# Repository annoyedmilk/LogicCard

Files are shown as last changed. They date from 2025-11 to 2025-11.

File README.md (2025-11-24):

# LogicCard




## Project Overview

The LogicCard is a compact and affordable FPGA development board featuring the Renesas SLG47910V FPGA with integrated USB programming via a CH552 microcontroller. The board includes an 11-pin Charlieplexed LED matrix (15×7 LEDs) and 4 user buttons, making it ideal for portable FPGA demonstrations and learning projects. The resistors for the LED matrix can be desoldered and the test points can be used for external applications.

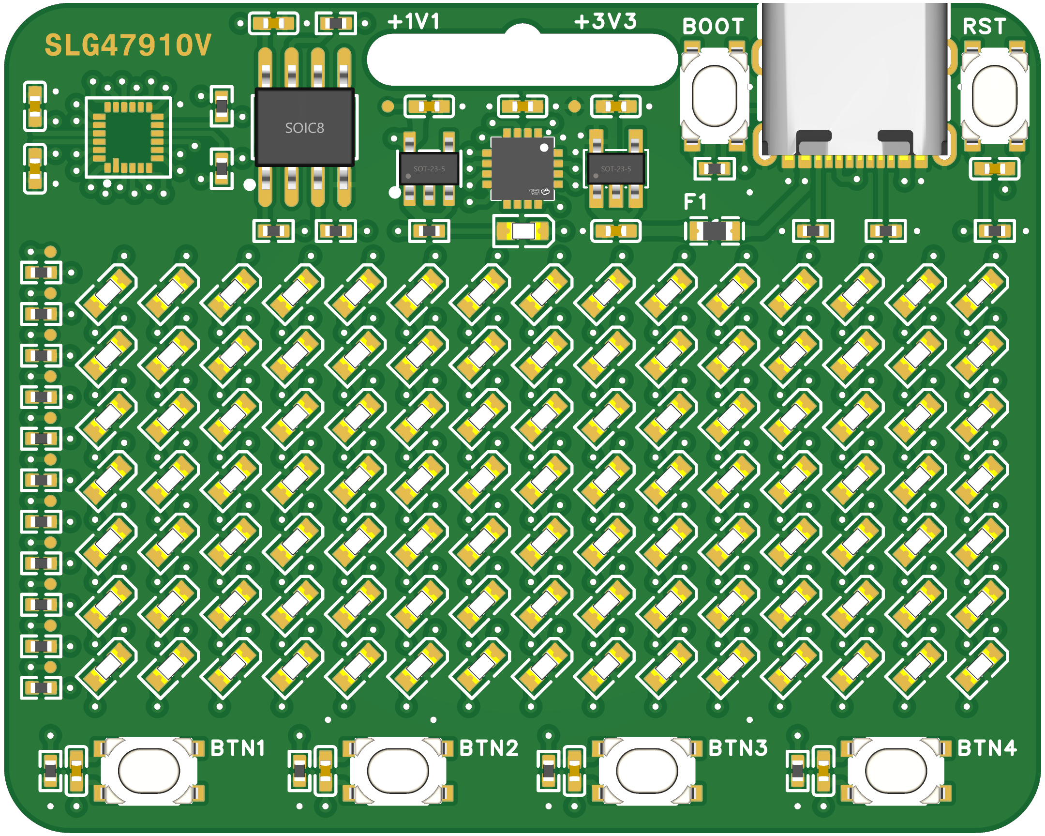
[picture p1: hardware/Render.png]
LogicCard 3D Render


### Key Features

- **FPGA**: Renesas SLG47910V (24-pin STQFN)
  - 1120 5-bit Look-Up Tables (LUTs)
  - 1120 D-type Flip-Flops (DFFs)
  - 5 kb distributed SRAM
  - 32 kb embedded Block RAM (BRAM)
  - 19 GPIOs available
  - 50 MHz on-chip oscillator
  - Phase-Locked Loop (PLL)
  - Advanced 6-input 2-output lookup table (LUT) structure for increased efficiency in high-usage designs
  - Low price that opens the low-density FPGA market to customers of all sizes (50 Cents at high volume)
  
- **USB Programming**: CH552 microcontroller implementing serprog protocol
- **Configuration Storage**: External SPI NOR Flash (W25Q80DVSNIG - 1 Mbit)
- **User Interface**: 15×7 LED matrix (105 LEDs) using 11 GPIO pins + 4 buttons
- **Power**: USB-powered with dual LDO regulation (5V → 3.3V → 1.1V)

---

## 2. Complete Pinout Tables

### 2.1 SLG47910V FPGA Pinout

| Pin | Name | Description | Net |
|-----|---|---|-----|
| 1 | GPIO10 | General Purpose I/O | CHRLY_2 |
| 2 | GPIO11 | General Purpose I/O | CHRLY_3 |
| 3 | GPIO12 | General Purpose I/O | CHRLY_4 |
| 4 | GPIO13 | General Purpose I/O | CHRLY_5 |
| 5 | GPIO14 | General Purpose I/O | CHRLY_6 |
| 6 | GPIO15 | General Purpose I/O | CHRLY_7 |
| 7 | GPIO16 | General Purpose I/O | CHRLY_8 |
| 8 | GPIO17 | General Purpose I/O | CHRLY_9 |
| 9 | GPIO18 | General Purpose I/O | CHRLY_10 |
| 10 | EN(nSLEEP) | Enable / Sleep (active low) | FPGA_EN |
| 11 | PWR(nRST) | Power / Reset (active low) | FPGA_RST |
| 12 | GND | Ground | GND |
| 13 | GPIO0 | General Purpose I/O | BUTTON_1 |
| 14 | GPIO1 | General Purpose I/O | BUTTON_2 |
| 15 | GPIO2 | General Purpose I/O | BUTTON_3 |
| 16 | GPIO3/SPI_CLK | GPIO 3 / SPI Clock | SPI_SCK |
| 17 | GPIO4/SPI_SS | GPIO 4 / SPI Chip Select | SPI_CS |
| 18 | GPIO5/SPI_SI | GPIO 5 / SPI Slave In | SPI_MISO |
| 19 | GPIO6/SPI_SO | GPIO 6 / SPI Slave Out | SPI_MOSI |
| 20 | GPIO7 | General Purpose I/O | BUTTON_4 |
| 21 | VDDIO | I/O Supply Voltage | +3.3V |
| 22 | VDDC | Core Supply Voltage | +1.1V |
| 23 | GPIO8 | General Purpose I/O | CHRLY_0 |
| 24 | GPIO9 | General Purpose I/O | CHRLY_1 |

### 2.2 CH552 Microcontroller Pinout

| Pin | Name | Description | Net |
|-----|---|---|-----|
| 1 | V33 | Internal USB power regulator | +3.3V |
| 2 | MOSI/PWM1/TIN3 | Port 1.5 | SPI_MOSI |
| 3 | T2_/CAP1_/SCS | Port 1.4 | SPI_CS |
| 4 | TXD1_/INT0/VBUS1 | Port 3.2 | LED |
| 5 | MISO/RXD1/TIN4 | Port 1.6 | SPI_MISO |
| 6 | SCK/TXD1/TIN5 | Port 1.7 | SPI_SCK |
| 7 | RST/T2EX_/CAP2_ | Reset | Reset |
| 8 | T2/CAP1/TIN0 | Port 1.0 | FPGA_RST |
| 9 | PWM2_/TXD | Port 3.1 | NC |
| 10 | PWM1_/RXD | Port 3.0 | NC |
| 11 | T2EX/CAP2/TIN1 | Port 1.1 | NC |
| 12 | INT1 | Port 3.3 | FPGA_EN |
| 13 | PWM2/RXD1_/T0 | Port 3.4 | NC |
| 14 | UDP | Port 3.6 | USB_D+ |
| 15 | UDM | Port 3.7 | USB_D- |
| 16 | VCC/VDD | Power | +3.3V |
| 17 | GND/VSS | GND | GND |

### 2.3 W25Q80DVSNIG Flash Memory Pinout

| Pin | Name | Description | Net |
|-----|---|---|-----|
| 1 | /CS | Chip Select (active low) | SPI_CS |
| 2 | DO(IO1) | Data Out / I/O 1 | SPI_MISO |
| 3 | /WP(IO2) | Write Protect (active low) / I/O 2 | Pull-up +3.3V |
| 4 | GND | Ground | GND |
| 5 | DI(IO0) | Data In / I/O 0 | SPI_MOSI |
| 6 | CLK | Clock | SPI_SCK |
| 7 | /HOLD(IO3) | Hold (active low) / I/O 3 | Pull-up +3.3V |
| 8 | VCC | Supply Voltage | +3.3V |

### 2.4 LED Matrix Charlieplex Connections

| FPGA GPIO | FPGA Pin | Matrix Pin | Function |
|---|---|---|---|
| GPIO8 | 23 | CHRLY_1 | Charlieplex Pin 1 |
| GPIO9 | 24 | CHRLY_2 | Charlieplex Pin 2 |
| GPIO10 | 1 | CHRLY_3 | Charlieplex Pin 3 |
| GPIO11 | 2 | CHRLY_4 | Charlieplex Pin 4 |
| GPIO12 | 3 | CHRLY_5 | Charlieplex Pin 5 |
| GPIO13 | 4 | CHRLY_6 | Charlieplex Pin 6 |
| GPIO14 | 5 | CHRLY_7 | Charlieplex Pin 7 |
| GPIO15 | 6 | CHRLY_8 | Charlieplex Pin 8 |
| GPIO16 | 7 | CHRLY_9 | Charlieplex Pin 9 |
| GPIO17 | 8 | CHRLY_10 | Charlieplex Pin 10 |
| GPIO18 | 9 | CHRLY_11 | Charlieplex Pin 11 |

### 2.5 User Button Connections

| Button | FPGA GPIO | FPGA Pin |
|---|---|---|
| BUTTON_1 | GPIO0 | 13 |
| BUTTON_2 | GPIO1 | 14 |
| BUTTON_3 | GPIO2 | 15 |
| BUTTON_4 | GPIO7 | 20 |

---

## 3. Configuration and Programming

### 3.1 Configuration Mode

The SLG47910V is configured to use **External SPI Flash Mode** (SPI Master):
- FPGA acts as SPI Master during configuration
- External SPI Flash (W25Q80) acts as SPI Slave
- GPIO4 (SPI_SS) has a 10kΩ pull-up ensuring HIGH at power-up

### 3.2 Programming Sequence

**Typical Operation Sequence:**
1. MCU asserts FPGA_RST to hold FPGA in reset
2. MCU takes control of SPI bus and writes configuration data to Flash
3. MCU releases FPGA_RST
4. FPGA boots and reads configuration from the same SPI Flash
5. FPGA becomes operational

### 3.3 Bitstream Size

- Required: **384 kbit** (48 KB) for full configuration
- Available: **1 Mbit** (128 KB) in W25Q80 Flash

---

## 4. LED Matrix Operation

### 4.1 Charlieplexing Details

The 15×7 LED matrix (105 LEDs) is controlled using **11 GPIO pins** via Charlieplexing:

**Formula:**
```
Maximum LEDs = n × (n - 1)
With 11 pins: 11 × 10 = 110 possible LEDs
Actual usage: 105 LEDs (15 rows × 7 columns)
```

### 4.2 Current Limiting

Each Charlieplex pin should have a series resistor (82Ω) for current limiting:
- Forward voltage (VF): ~1.8V (yellow LEDs)
- Forward current (IF): ~10 mA for visibility
- These resistors can be desoldered to use test points for external applications
- As one GPIO drives the anode and another the cathode, the total resistance is 2 × 82Ω = 164Ω

---

## 5. CH552 USB Programmer

### 5.1 serprog Protocol Implementation

The CH552 firmware implements the serprog protocol for flashrom compatibility:

**Supported Features:**
- SPI Master interface
- FPGA reset/enable control with bus arbitration
- Visual LED feedback during programming operations
- Compatible with standard flashrom tool

**USB Identifiers:**
- Vendor ID: 0x1a86 (WCH)
- Product ID: 0x5722
- Device Class: CDC
- Product String: "ch552-serprog"

**LED Behavior:**
- **On** during power-up and USB enumeration
- **Blinks** during USB configuration
- **Off** when idle and ready for commands
- **On** during flash programming operations (CH552 controls SPI bus)
- **Off** when FPGA is enabled (FPGA controls SPI bus)

### 5.2 Programming Commands

```bash
# Flash FPGA bitstream using flashrom
flashrom -p serprog:dev=/dev/ttyACM0 -w FPGA_bitstream_FLASH_MEM.bin

# Read current configuration
flashrom -p serprog:dev=/dev/ttyACM0 -r current_config.bin

# Erase flash
flashrom -p serprog:dev=/dev/ttyACM0 -E
```

---

## 6. Available FPGA Examples

The project includes two ready-to-use FPGA bitstreams:

### 6.1 Blink Example
- **Location**: [examples/blink/](examples/blink/)
- **Description**: Simple LED blinking demo using Charlieplex configuration
- **Features**: Single LED blinking at 2Hz using 2 GPIO pins
- **Bitstream**: [examples/blink/ffpga/build/bitstream/FPGA_bitstream_FLASH_MEM_1MB.bin](examples/blink/ffpga/build/bitstream/FPGA_bitstream_FLASH_MEM_1MB.bin)

### 6.2 Demo Project
- **Location**: [examples/demo/demo.ffpga](examples/demo/demo.ffpga)
- **Description**: Full 15×7 LED matrix with ripple effect animation
- **Features**:
  - 105-LED Charlieplexed matrix (15 rows × 7 columns)
  - Button controls for pattern inversion, speed control, and pause/play
  - Uses all 11 Charlieplex GPIO pins
- **Bitstream**: [examples/demo/ffpga/build/bitstream/FPGA_bitstream_FLASH_MEM_1MB.bin](examples/demo/ffpga/build/bitstream/FPGA_bitstream_FLASH_MEM_1MB.bin)

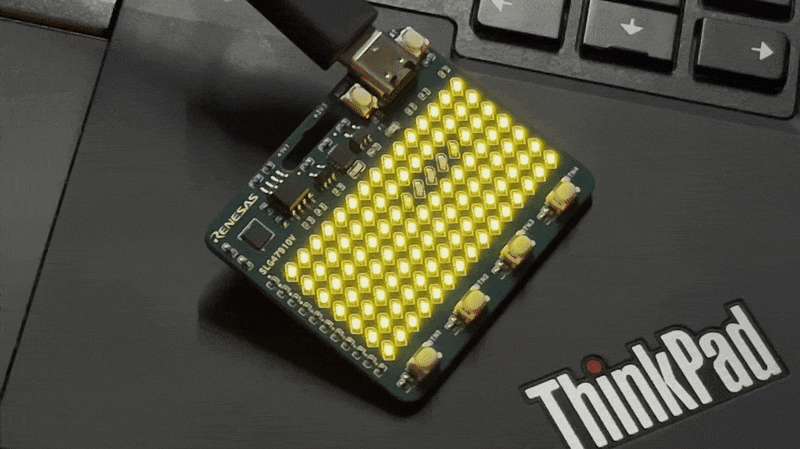
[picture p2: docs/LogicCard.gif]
LogicCard Demo Animation


---

## 7. Design Files Structure

```
LogicCard/
├── hardware/               # Hardware design files
│   ├── BOM.csv            # Bill of Materials
│   ├── Schematic.pdf      # Circuit schematic
│   ├── 3D.step            # 3D model (STEP format)
│   └── Render.png         # 3D render preview
├── firmware/              # CH552 firmware source code
│   ├── ch552_serprog/     # serprog protocol implementation
│   │   └── main.c         # Main firmware source
│   ├── include/           # Shared header files
│   └── build/             # Compiled firmware binaries
│       └── ch552-serprog.bin
├── examples/              # Example FPGA projects
│   ├── blink/             # Simple LED blink example
│   │   ├── blink.ffpga    # GoConfigure project file
│   │   └── ffpga/         # FFPGA build artifacts
│   │       ├── src/       # Verilog source files
│   │       │   └── blink.v
│   │       └── build/     # Build output directory
│   │           └── bitstream/
│   │               ├── FPGA_bitstream_FLASH_MEM.bin (48KB)
│   │               └── FPGA_bitstream_FLASH_MEM_1MB.bin (1MB padded)
│   └── demo/              # LED matrix demo with ripple effect
│       ├── demo.ffpga     # GoConfigure project file
│       └── ffpga/         # FFPGA build artifacts
│           ├── src/       # Verilog source files
│           │   └── demo.v
│           └── build/     # Build output directory
│               └── bitstream/
│                   ├── FPGA_bitstream_FLASH_MEM.bin (48KB)
│                   └── FPGA_bitstream_FLASH_MEM_1MB.bin (1MB padded)
└── docs/                  # Documentation and datasheets
    ├── CH552.PDF          # CH552 microcontroller datasheet
    ├── SLG47910.pdf       # SLG47910V FPGA datasheet
    ├── W25Q80DV.pdf       # W25Q80 Flash memory datasheet
    └── LogicCard.gif      # Demo animation
```

---

## 8. Quick Start Guide

### 8.1 Hardware Setup
1. Connect LogicCard to computer via USB-C cable
2. The board should enumerate as a USB device

### 8.2 CH552 Firmware Update (First Time Setup)

The CH552 microcontroller needs to be programmed with the serprog firmware on first use.

#### Installing wchisp (Recommended for Linux)

```bash
# Install from cargo (Rust package manager)
cargo install wchisp

# Set udev rules for non-root access
sudo tee /etc/udev/rules.d/50-wchisp.rules > /dev/null <<EOF
SUBSYSTEM=="usb", ATTRS{idVendor}=="4348", ATTRS{idProduct}=="55e0", MODE="0666"
EOF
sudo udevadm control --reload-rules
```

**Arch Linux:**
```bash
yay -S wchisp
```

#### Flashing CH552 Firmware

1. Hold the BOOT button and connect the board to your computer
2. Flash the firmware:
   ```bash
   wchisp flash firmware/build/ch552-serprog.bin
   ```
3. Disconnect and reconnect the board (without holding BOOT)
4. The board should now appear as `/dev/ttyACM0`

For more details on wchisp, see the [official repository](https://github.com/ch32-rs/wchisp).

### 8.3 Programming the FPGA

#### Try the Pre-built Examples

1. Install flashrom:
   ```bash
   sudo apt install flashrom
   ```

2. Flash one of the ready-to-use examples:
   ```bash
   # Blink example
   flashrom -p serprog:dev=/dev/ttyACM0 -w examples/blink/ffpga/build/bitstream/FPGA_bitstream_FLASH_MEM_1MB.bin

   # Or the full LED matrix demo
   flashrom -p serprog:dev=/dev/ttyACM0 -w examples/demo/ffpga/build/bitstream/FPGA_bitstream_FLASH_MEM_1MB.bin
   ```

3. The FPGA automatically configures and runs after programming

#### Build Your Own FPGA Design

1. Create your design using Renesas GoConfigure tool
2. Generate bitstream file (`.bin`)
3. **Pad the bitstream to 1MB** (flashrom requires full chip-size images):
   ```bash
   # Pad bitstream to match W25Q80 flash size (1MB)
   cp FPGA_bitstream_FLASH_MEM.bin FPGA_bitstream_FLASH_MEM_1MB.bin
   truncate -s 1M FPGA_bitstream_FLASH_MEM_1MB.bin
   ```
4. Flash using: `flashrom -p serprog:dev=/dev/ttyACM0 -w FPGA_bitstream_FLASH_MEM_1MB.bin`

**Note:** The FPGA only uses the first 48KB (384 kbit) of the flash for configuration. The W25Q80 flash chip is 1MB (1,048,576 bytes), so flashrom requires the image to be padded to the full chip size.

---

## 9. Specifications Summary

| Parameter | Value |
|---|---|
| FPGA Logic | 1120 LUTs, 1120 DFFs |
| Memory | 5kb SRAM + 32kb BRAM |
| I/O Pins | 19 GPIOs |
| Clock | 50 MHz internal oscillator + PLL |
| Flash Storage | 1 Mbit SPI NOR (W25Q80) |
| USB Interface | Full Speed (12 Mbps) |
| LED Matrix | 15×7 (105 LEDs) |
| User Buttons | 4 |
| Power | USB 5V → 3.3V (TLV70233) → 1.1V (TLV74311) |
| Voltage Regulators | TLV70233DBVR (3.3V), TLV74311PDBVR (1.1V) |
| Programming | serprog/flashrom compatible |

---

## 10. Contributing

This is an open-source hardware project. Contributions, suggestions, and feedback are welcome!

### How to Contribute
- Report issues or suggest features via GitHub Issues
- Submit pull requests for improvements
- Help improve documentation

---

## 11. Resources & References

### Datasheets
- [SLG47910V Datasheet](https://www.renesas.com/document/dst/slg47910-datasheet) - Renesas FPGA
- [W25Q80DV Datasheet](https://www.winbond.com/resource-files/w25q80dv_revg_07212015.pdf) - Flash Memory
- [CH552 Datasheet](https://www.wch-ic.com/downloads/CH552DS1_PDF.html) - USB MCU

### Software Tools
- [GoConfigure](https://www.renesas.com/en/software-tool/go-configure-software-hub): Official Renesas FPGA development tool
- [flashrom](https://github.com/flashrom/flashrom): Open-source flash programmer
- [SDCC](https://sdcc.sourceforge.net/): Small Device C Compiler for CH552

### Example Code
- [ch552_serprog](https://github.com/ieiao/ch554_sdcc) - CH552 serprog implementation
- [Charlieplexing Examples](https://en.wikipedia.org/wiki/Charlieplexing) - LED matrix control

### Alternative Development Workflows
- [LogicCard-VHDL](https://github.com/annoyedmilk/LogicCard-VHDL) - VHDL synthesis workflow using GHDL/Yosys for those who prefer VHDL over Verilog

---

## 12. License

This project is licensed under the **CERN Open Hardware Licence Version 2 - Weakly Reciprocal (CERN-OHL-W)**. See the [LICENSE](LICENSE) file for full details.

## 13. Credits & Acknowledgments

- **Renesas** for providing SLG47910V FPGA samples and development tools
- **ieiao** for the [CH552 serprog implementation](https://github.com/ieiao/ch554_sdcc)
- **ch32-rs team** for the [wchisp tool](https://github.com/ch32-rs/wchisp)
- The open-source hardware and FPGA community

## 14. Contact & Support

For questions, issues, or suggestions:
- Open an issue on GitHub
- Check the [docs/](docs/) folder for datasheets and technical documentation
- Review the schematic and BOM in the [hardware/](hardware/) folder

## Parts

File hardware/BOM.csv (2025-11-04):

No. | Quantity | Comment | Designator | Footprint | Value | Manufacturer Part | Manufacturer | Supplier Part | Supplier
1 | 13 | Test-Point | +1V1,+3V3,TP1,TP2,TP3,TP4,TP5,TP6,TP7,TP8,TP9,TP10,TP11 | Test-Point-0.5mm
2 | 6 | SKRPACE010 | BOOT,BTN1,BTN2,BTN3,BTN4,RST | KEY-SMD_4P-L4.2-W3.2-P2.20-LS4.6 |  | SKRPACE010 | ALPSALPINE(阿尔卑斯阿尔派) | C139797 | LCSC
3 | 1 | TYPE-C 16PIN 2MD(073) | C1 | USB-C-SMD_TYPE-C-6PIN-2MD-073 |  | TYPE-C 16PIN 2MD(073) | SHOU HAN(首韩) | C2765186 | LCSC
4 | 12 | 1uF | C5,C6,C8,C9,C10,C11,C12,C14,C15,C16,C17,C18 | C0402 | 1uF | GRM155Z71A105KE01D | muRata(村田) | C528974 | LCSC
5 | 1 | MF-FSMF035X-2 | F1 | F0603 |  | MF-FSMF035X-2 | BOURNS | C116602 | LCSC
6 | 106 | 19-213/Y2C-CQ2R2L/3T(CY) | LED1,LED2,LED3,LED4,LED5,LED6,LED7,LED8,LED9,LED10,LED11,LED12,LED13,LED14,LED15,LED16,LED17,LED18,LED19,LED20,LED21,LED22,LED23,LED24,LED25,LED26,LED27,LED28,LED29,LED30,LED31,LED32,LED33,LED34,LED35,LED36,LED37,LED38,LED39,LED40,LED41,LED42,LED43,LED44,LED45,LED46,LED47,LED48,LED49,LED50,LED51,LED52,LED53,LED54,LED55,LED56,LED57,LED58,LED59,LED60,LED61,LED62,LED63,LED64,LED65,LED66,LED67,LED68,LED69,LED70,LED71,LED72,LED73,LED74,LED75,LED76,LED77,LED78,LED79,LED80,LED81,LED82,LED83,LED84,LED85,LED86,LED87,LED88,LED89,LED90,LED91,LED92,LED93,LED94,LED95,LED96,LED97,LED98,LED99,LED100,LED101,LED102,LED103,LED104,LED105,LED106 | LED0603-RD-YELLOW |  | 19-213/Y2C-CQ2R2L/3T(CY) | EVERLIGHT(亿光) | C72038 | LCSC
7 | 2 | 5.1kΩ | R18,R19 | R0402 | 5.1kΩ | RC0402JR-075K1L | YAGEO(国巨) | C105873 | LCSC
8 | 11 | 10kΩ | R23,R24,R36,R37,R38,R39,R53,R54,R55,R56,R57 | R0402 | 10kΩ | RC0402FR-0710KL | YAGEO(国巨) | C60490 | LCSC
9 | 11 | 82Ω | R41,R42,R43,R44,R45,R46,R47,R48,R49,R50,R51 | R0402 | 82Ω | RC0402FR-0782RL | YAGEO(国巨) | C163453 | LCSC
10 | 1 | 180Ω | R52 | R0402 | 180Ω | RC0402FR-07180RL | YAGEO(国巨) | C138045 | LCSC
11 | 1 | SLG47910V | U1 | STQFN-24_L3.0-W3.0-P0.4_SLG47910V |  | SLG47910V |  | C9900234634 | LCSC
12 | 1 | CH552P | U2 | VQFN-16_L3.0-W3.0-P0.50-BL-EP1.7 |  | CH552P | WCH(南京沁恒) | C968536 | LCSC
13 | 1 | W25Q80DVSNIG | U3 | SOIC-8_L4.9-W3.9-P1.27-LS6.0-BL |  | W25Q80DVSNIG | Winbond(华邦) | C115408 | LCSC
14 | 1 | TLV70233DBVR | U4 | SOT-23-5_L3.0-W1.7-P0.95-LS2.8-BR |  | TLV70233DBVR | TI(德州仪器) | C26833 | LCSC
15 | 1 | TLV74311PDBVR | U5 | SOT-23-5_L3.0-W1.7-P0.95-LS2.8-BL |  | TLV74311PDBVR | TI(德州仪器) | C485147 | LCSC

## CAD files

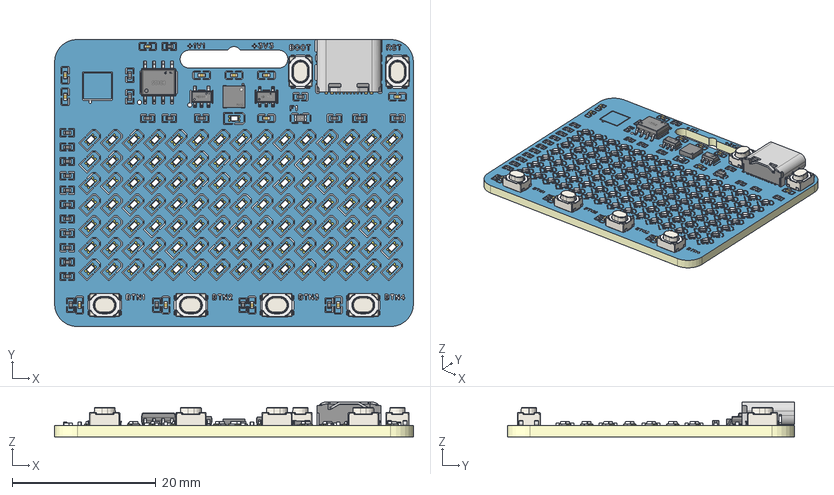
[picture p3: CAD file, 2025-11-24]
hardware/3D.step
50.0 x 40.0 x 4.87 mm
Board~ELZ3
TopCopper~ELZ3
BottomCopper~ELZ3
TopSilkscreen~ELZ3
BottomSilkscreen~ELZ3
TopFpcStiffener~ELZ3
BottomFpcStiffener~ELZ3
R0402~R0402_L1.0-W0.5-H0.4~ELZ3 x 25
F0603~F0603_L1.7-W0.9-H0.7~ELZ3
KEY-SMD_4P-L4.2-W3.2-P2.20-LS4.6~KEY-SMD_ 4P-L4.2-W3.2-H2.5-LS4.6-P2.2~ELZ3 x 6
USB-C-SMD_TYPE-C-6PIN-2MD-073~USB-C-SMD_TYPE-C-6PIN-2MD-073~ELZ3
C0402~C0402_L1.0-W0.5-H0.5~ELZ3 x 12
SOT-23-5_L3.0-W1.7-P0.95-LS2.8-BR~SOT-23-5_ L2.9-W1.6-H1.1-LS2.8-P0.95~ELZ3
SOT-23-5_L3.0-W1.7-P0.95-LS2.8-BL~SOT-23-5_ L2.9-W1.6-H1.1-LS2.8-P0.95~ELZ3
SOIC-8_L4.9-W3.9-P1.27-LS6.0-BL~SOIC-8_L4.9-W3.9-H1.7-LS6.0-P1.27~ELZ3
VQFN-16_L3.0-W3.0-P0.50-BL-EP1.7~VQFN-16_L3.0-W3.0-P0.50-BL-EP1.7~ELZ3
LED0603-RD-YELLOW~LED0603-RD-YELLOW~ELZ3 x 106

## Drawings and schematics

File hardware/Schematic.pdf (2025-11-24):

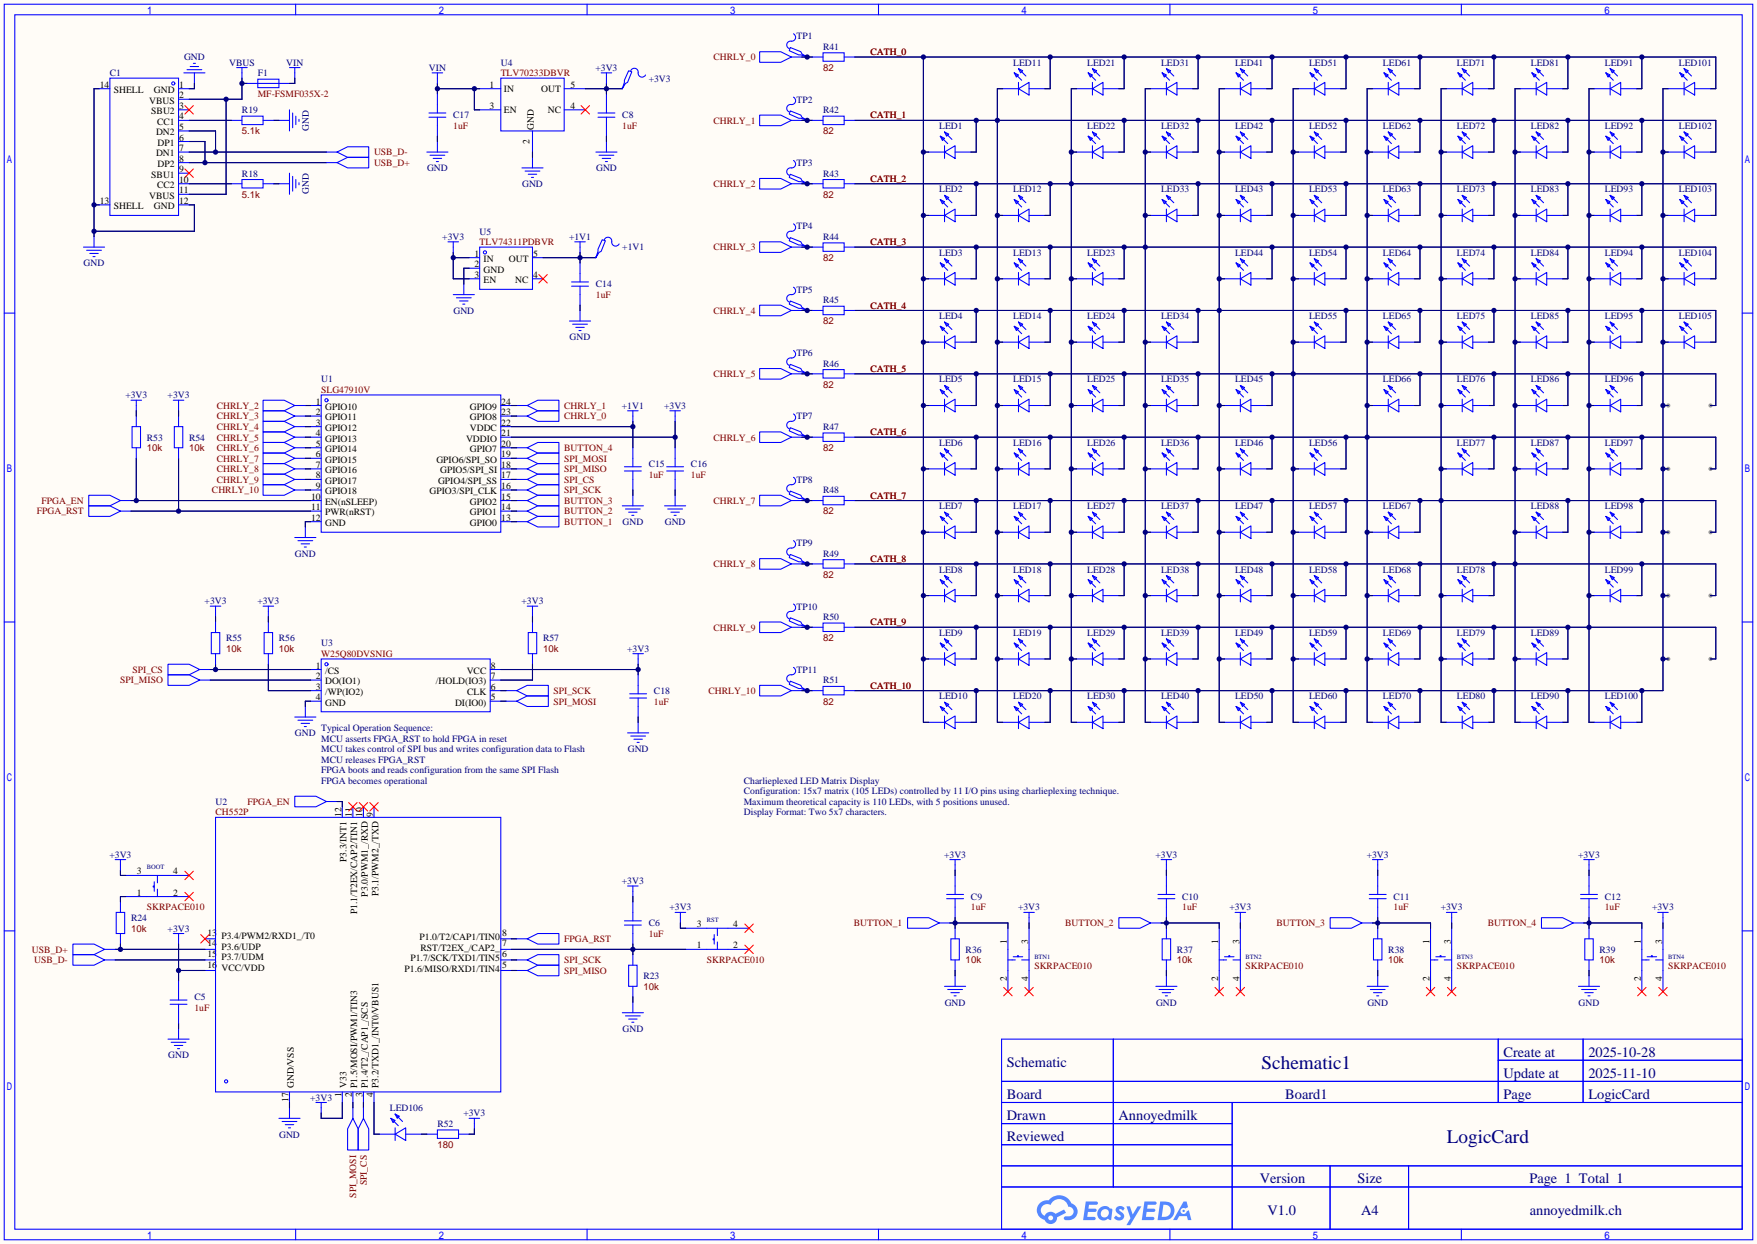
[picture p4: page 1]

Typical Operation Sequence:
GND
MCU asserts FPGA_RST to hold FPGA in reset
MCU takes control of SPI bus and writes configuration data to Flash
MCU releases FPGA_RST
FPGA boots and reads configuration from the same SPI Flash

Configuration: 15x7 matrix (105 LEDs) controlled by 11 I/O pins using charlieplexing technique.
Maximum theoretical capacity is 110 LEDs, with 5 positions unused.
Display Format: Two 5x7 characters.

Schematic | Schematic1 | Create at | 2025-10-28

Update at | 2025-11-10

Board | Board1 | Page | LogicCard
Drawn | Annoyedmilk | LogicCard
Reviewed

Version | Size | Page 1 Total 1

V1.0 | A4 | annoyedmilk.ch

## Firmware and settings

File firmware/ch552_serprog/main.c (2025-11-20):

/********************************** (C) COPYRIGHT *******************************
* File Name          : CDC.C
* Author             : ieiao
* Modified by        : annoyedmilk
* Version            : V1.1
* Date               : 2017/03/01
* Modified Date      : 2025/11/03
* Description        : CH552 serprog implementation for use with flashrom
*                      V1.1: Added FPGA reset/enable control for LogicCard project
*                            - FPGA_RST (Port 1.0) and FPGA_EN (Port 3.3) control
*                            - Automatic FPGA reset before flash operations
*                            - Automatic FPGA enable after flash programming
*                            - LED activity indicator (active low)
*******************************************************************************/
#include <stdint.h>
#include <stdio.h>
#include <string.h>

#include <ch554.h>
#include <ch554_usb.h>
#include <spi.h>
#include <debug.h>
#include "serprog.h"

#define LED_PIN  2
SBIT(LED, 0xb0, LED_PIN);     // Port 3.2 - LED
#define CS_PIN  4
SBIT(CS, 0x90, CS_PIN);       // Port 1.4 - SPI_CS
#define FPGA_RST_PIN  0
SBIT(FPGA_RST, 0x90, FPGA_RST_PIN);  // Port 1.0 - FPGA_RST
#define FPGA_EN_PIN  3
SBIT(FPGA_EN, 0xb0, FPGA_EN_PIN);    // Port 3.3 - FPGA_EN

#define PGMNAME "LogicCard"
#define CMD_MAP (\
    (1L << S_CMD_NOP)        | \
    (1L << S_CMD_Q_IFACE)    | \
    (1L << S_CMD_Q_CMDMAP)   | \
    (1L << S_CMD_Q_PGMNAME)  | \
    (1L << S_CMD_Q_SERBUF)   | \
    (1L << S_CMD_Q_BUSTYPE)  | \
    (1L << S_CMD_Q_CHIPSIZE) | \
    (1L << S_CMD_Q_OPBUF)    | \
    (1L << S_CMD_Q_WRNMAXLEN)| \
    (1L << S_CMD_SYNCNOP)    | \
    (1L << S_CMD_Q_RDNMAXLEN)| \
    (1L << S_CMD_S_BUSTYPE)  | \
    (1L << S_CMD_O_SPIOP)    | \
    (1L << S_CMD_S_PIN_STATE)  \
)
#define BUS_SPI (1 << 3)

// Flash chip specifications for W25Q80DVSNIG
// 1 Mbit = 128 KB = 2^17 bytes
#define CHIP_SIZE 17          // log2(128*1024) = 17
#define OPBUF_SIZE 64         // Operation buffer size in bytes
#define MAX_WRITE_N 64        // Maximum write-N length
#define MAX_READ_N 65535      // Maximum read-N length

__xdata __at (0x0000) uint8_t  Ep0Buffer[DEFAULT_ENDP0_SIZE];      // Endpoint 0 OUT & IN buffer, must be an even address
__xdata __at (0x0040) uint8_t  Ep1Buffer[DEFAULT_ENDP1_SIZE];       //Endpoint 1 upload buffer
__xdata __at (0x0080) uint8_t  Ep2Buffer[2*MAX_PACKET_SIZE];        //Endpoint 2 IN & OUT buffer, must be an even address
__xdata __at (0x0100) uint8_t  Ep2Buffer_1[2*MAX_PACKET_SIZE];        //Endpoint 2 IN & OUT buffer, must be an even address

uint16_t SetupLen;
uint8_t   SetupReq, UsbConfig;
const uint8_t * pDescr;                                                       //USB configuration flag
#define UsbSetupBuf     ((PUSB_SETUP_REQ)Ep0Buffer)

#define  SET_LINE_CODING                0X20            // Configures DTE rate, stop-bits, parity, and number-of-character
#define  GET_LINE_CODING                0X21            // This request allows the host to find out the currently configured line coding.
#define  SET_CONTROL_LINE_STATE         0X22            // This request generates RS-232/V.24 style control signals.


/*设备描述符*/
__code uint8_t DevDesc[] = {0x12,0x01,0x10,0x01,0x02,0x00,0x00,DEFAULT_ENDP0_SIZE,
                            0x86,0x1a,0x22,0x57,0x00,0x01,0x01,0x02,
                            0x03,0x01
                           };
__code uint8_t CfgDesc[] ={
    0x09,0x02,0x43,0x00,0x02,0x01,0x00,0xa0,0x32,             //Configuration descriptor (two interfaces)
// The following is the interface 0 (CDC interface) descriptor
    0x09,0x04,0x00,0x00,0x01,0x02,0x02,0x01,0x00, // CDC interface descriptor (one endpoint)
    //The following is the function descriptor
    0x05,0x24,0x00,0x10,0x01,                                 //Function descriptor (header)
    0x05,0x24,0x01,0x00,0x00,                                 //Management descriptor (no data interface) 03 01
    0x04,0x24,0x02,0x02,                                      //stand by,Set_Line_Coding、Set_Control_Line_State、Get_Line_Coding、Serial_State
    0x05,0x24,0x06,0x00,0x01,                                 //CDC interface numbered 0; data interface numbered 1
    0x07,0x05,0x81,0x03,0x08,0x00,0xFF,                       //Interrupt upload endpoint descriptor
    //The following is the interface 1 (data interface) descriptor
    0x09,0x04,0x01,0x00,0x02,0x0a,0x00,0x00,0x00,             //Data interface descriptor
    0x07,0x05,0x02,0x02,0x40,0x00,0x00,                       //Endpoint descriptor
    0x07,0x05,0x82,0x02,0x40,0x00,0x00,                       //Endpoint descriptor
};
/*字符串描述符*/
unsigned char  __code LangDes[]={0x04,0x03,0x09,0x04};           //Language descriptor
unsigned char  __code SerDes[]={                                 //Serial number string descriptor
                                                                 0x0e,0x03,
                                                                 0x32,0x00,0x30,0x00,0x32,0x00,0x32,0x00,0x30,0x00,0x31,0x00,
                               };
unsigned char  __code Prod_Des[]={                                //Product string descriptor
                                                                  0x1C,0x03,
                                                                  0x63,0x00,0x68,0x00,0x35,0x00,0x35,0x00,0x32,0x00,0x2D,0x00,
                                                                  0x73,0x00,0x65,0x00,0x72,0x00,0x70,0x00,0x72,0x00,0x6F,0x00,
                                                                  0x67,0x00,
                                 };
unsigned char  __code Manuf_Des[]={
    0x0c,0x03,
    0x69,0x00,0x65,0x00,0x69,0x00,0x61,0x00,0x6f,0x00,
};

//cdc参数
__xdata uint8_t LineCoding[7]={0x00,0xe1,0x00,0x00,0x00,0x00,0x08};   //The initial baud rate is 57600, 1 stop bit, no parity, 8 data bits.



volatile __idata uint8_t USBByteCount = 0;      //Represents the data received by the USB endpoint
volatile __idata uint8_t UpPoint2_Busy  = 0;   //Whether the upload endpoint is busy

/*******************************************************************************
* Function Name  : USBDeviceCfg()
* Description    : USB device mode configuration
* Input          : None
* Output         : None
* Return         : None
*******************************************************************************/
void USBDeviceCfg()
{
    USB_CTRL = 0x00;                                                           //Clear USB control register
    USB_CTRL &= ~bUC_HOST_MODE;                                                //This bit selects the device mode
    USB_CTRL |=  bUC_DEV_PU_EN | bUC_INT_BUSY | bUC_DMA_EN;                    //USB device and internal pull-up enable, automatically return to NAK before interrupt flag is cleared
    USB_DEV_AD = 0x00;                                                         //Device address initialization
    //     USB_CTRL |= bUC_LOW_SPEED;
    //     UDEV_CTRL |= bUD_LOW_SPEED;                                                //Select low speed 1.5M mode
    USB_CTRL &= ~bUC_LOW_SPEED;
    UDEV_CTRL &= ~bUD_LOW_SPEED;                                             //Select full speed 12M mode, the default mode
    UDEV_CTRL = bUD_PD_DIS;  // Disable DP / DM pull-down resistor
    UDEV_CTRL |= bUD_PORT_EN;                                                  //Enable physical port
}
/*******************************************************************************
* Function Name  : USBDeviceIntCfg()
* Description    : USB device mode interrupt initialization
* Input          : None
* Output         : None
* Return         : None
*******************************************************************************/
void USBDeviceIntCfg()
{
    USB_INT_EN |= bUIE_SUSPEND;                                               //Enable device suspend interrupt
    USB_INT_EN |= bUIE_TRANSFER;                                              //Enable USB transfer completion interrupt
    USB_INT_EN |= bUIE_BUS_RST;                                               //Enable device mode USB bus reset interrupt
    USB_INT_FG |= 0x1F;                                                       //Clear interrupt flag
    IE_USB = 1;                                                               //Enable USB interrupt
    EA = 1;                                                                   //Allow microcontroller interrupt
}
/*******************************************************************************
* Function Name  : USBDeviceEndPointCfg()
* Description    : USB device mode endpoint configuration, simulation compatible HID device, in addition to endpoint 0 control transmission, also includes endpoint 2 batch upload
* Input          : None
* Output         : None
* Return         : None
*******************************************************************************/
void USBDeviceEndPointCfg()
{
    // TODO: Is casting the right thing here? What about endianness?
    UEP1_DMA = (uint16_t) Ep1Buffer;                                                      //Endpoint 1 sends data transfer address
    UEP2_DMA = (uint16_t) Ep2Buffer;                                                      //Endpoint 2 IN data transfer address
    UEP2_3_MOD = 0xCC;                                                         //Endpoint 2/3 single buffer transceiver enable
    UEP2_CTRL = bUEP_AUTO_TOG | UEP_T_RES_NAK | UEP_R_RES_ACK;                 //Endpoint 2 automatically flips the synchronization flag, IN transaction returns NAK, OUT returns ACK

    UEP1_CTRL = bUEP_AUTO_TOG | UEP_T_RES_NAK;                                 //Endpoint 1 automatically flips the synchronization flag, IN transaction returns NAK
    UEP0_DMA = (uint16_t) Ep0Buffer;                                                      //Endpoint 0 data transfer address
    UEP4_1_MOD = 0X40;                                                         //Endpoint 1 upload buffer; endpoint 0 single 64-byte send and receive buffer
    UEP0_CTRL = UEP_R_RES_ACK | UEP_T_RES_NAK;                                 //Manual flip, OUT transaction returns ACK, IN transaction returns NAK
}
/*******************************************************************************
* Function Name  : DeviceInterrupt()
* Description    : CH559USB interrupt processing function
*******************************************************************************/
void DeviceInterrupt(void) __interrupt (INT_NO_USB)                       //USB interrupt service routine, using register set 1
{
    uint16_t len;
    if(UIF_TRANSFER)                                                            //USB transfer complete flag
    {
        switch (USB_INT_ST & (MASK_UIS_TOKEN | MASK_UIS_ENDP))
        {
        case UIS_TOKEN_IN | 1:                                                  //endpoint 1# 端点中断上传
            UEP1_T_LEN = 0;
            UEP1_CTRL = UEP1_CTRL & ~ MASK_UEP_T_RES | UEP_T_RES_NAK;           //默认应答NAK
            break;
        case UIS_TOKEN_IN | 2:                                                  //endpoint 2# 端点批量上传
        {
            UEP2_T_LEN = 0;                                                    //预使用发送长度一定要清空
            UEP2_CTRL = UEP2_CTRL & ~ MASK_UEP_T_RES | UEP_T_RES_NAK;           //默认应答NAK
            UpPoint2_Busy = 0;                                                  //清除忙标志
        }
            break;
        case UIS_TOKEN_OUT | 2:                                                 //endpoint 3# 端点批量下传
            if ( U_TOG_OK )                                                     // 不同步的数据包将丢弃
            {
                USBByteCount = USB_RX_LEN;                          // Grads length of recieved data
                UEP2_CTRL = UEP2_CTRL & ~ MASK_UEP_R_RES | UEP_R_RES_NAK;       //NAK after receiving a packet of data, the main function finishes processing, and the main function modifies the response mode
            }
            break;
        case UIS_TOKEN_SETUP | 0:                                                //SETUP事务
            len = USB_RX_LEN;
            if(len == (sizeof(USB_SETUP_REQ)))
            {
                SetupLen = ((uint16_t)UsbSetupBuf->wLengthH<<8) | (UsbSetupBuf->wLengthL);
                len = 0;                                                      // 默认为成功并且上传0长度
                SetupReq = UsbSetupBuf->bRequest;
                if ( ( UsbSetupBuf->bRequestType & USB_REQ_TYP_MASK ) != USB_REQ_TYP_STANDARD )//非标准请求
                {
                    switch( SetupReq )
                    {
                    case GET_LINE_CODING:   //0x21  currently configured
                        pDescr = LineCoding;
                        len = sizeof(LineCoding);
                        len = SetupLen >= DEFAULT_ENDP0_SIZE ? DEFAULT_ENDP0_SIZE : SetupLen;  // 本次传输长度
                        memcpy(Ep0Buffer,pDescr,len);
                        SetupLen -= len;
                        pDescr += len;
                        break;
                    case SET_CONTROL_LINE_STATE:  //0x22  generates RS-232/V.24 style control signals
                        break;
                    case SET_LINE_CODING:      //0x20  Configure
                        break;
                    default:
                        len = 0xFF;  								 					                 /*Command not supported*/
                        break;
                    }
                }
                else                                                             //Standard request
                {
                    switch(SetupReq)                                             //Request code
                    {
                    case USB_GET_DESCRIPTOR:
                        switch(UsbSetupBuf->wValueH)
                        {
                        case 1:                                                       //设备描述符
                            pDescr = DevDesc;                                         //把设备描述符送到要发送的缓冲区
                            len = sizeof(DevDesc);
                            break;
                        case 2:                                                        //配置描述符
                            pDescr = CfgDesc;                                          //把设备描述符送到要发送的缓冲区
                            len = sizeof(CfgDesc);
                            break;
                        case 3:
                            if(UsbSetupBuf->wValueL == 0)
                            {
                                pDescr = LangDes;
                                len = sizeof(LangDes);
                            }
                            else if(UsbSetupBuf->wValueL == 1)
                            {
                                pDescr = Manuf_Des;
                                len = sizeof(Manuf_Des);
                            }
                            else if(UsbSetupBuf->wValueL == 2)
                            {
                                pDescr = Prod_Des;
                                len = sizeof(Prod_Des);
                            }
                            else
                            {
                                pDescr = SerDes;
                                len = sizeof(SerDes);
                            }
                            break;
                        default:
                            len = 0xff;                                                //Unsupported command or error
                            break;
                        }
                        if ( SetupLen > len )
                        {
                            SetupLen = len;    //Limit total length
                        }
                        len = SetupLen >= DEFAULT_ENDP0_SIZE ? DEFAULT_ENDP0_SIZE : SetupLen;                            //This transmission length
                        memcpy(Ep0Buffer,pDescr,len);                                  //Load upload data
                        SetupLen -= len;
                        pDescr += len;
                        break;
                    case USB_SET_ADDRESS:
                        SetupLen = UsbSetupBuf->wValueL;                              //Temporary storage of USB device address
                        break;
                    case USB_GET_CONFIGURATION:
                        Ep0Buffer[0] = UsbConfig;
                        if ( SetupLen >= 1 )
                        {
                            len = 1;
                        }
                        break;
                    case USB_SET_CONFIGURATION:
                        UsbConfig = UsbSetupBuf->wValueL;
                        break;
                    case USB_GET_INTERFACE:
                        break;
                    case USB_CLEAR_FEATURE:                                            //Clear Feature
                        if( ( UsbSetupBuf->bRequestType & 0x1F ) == USB_REQ_RECIP_DEVICE )                  /* Remove device */
                        {
                            if( ( ( ( uint16_t )UsbSetupBuf->wValueH << 8 ) | UsbSetupBuf->wValueL ) == 0x01 )
                            {
                                if( CfgDesc[ 7 ] & 0x20 )
                                {
                                    /* 唤醒 */
                                }
                                else
                                {
                                    len = 0xFF;                                        /* 操作失败 */
                                }
                            }
                            else
                            {
                                len = 0xFF;                                            /* 操作失败 */
                            }
                        }
                        else if ( ( UsbSetupBuf->bRequestType & USB_REQ_RECIP_MASK ) == USB_REQ_RECIP_ENDP )// 端点
                        {
                            switch( UsbSetupBuf->wIndexL )
                            {
                            case 0x83:
                                UEP3_CTRL = UEP3_CTRL & ~ ( bUEP_T_TOG | MASK_UEP_T_RES ) | UEP_T_RES_NAK;
                                break;
                            case 0x03:
                                UEP3_CTRL = UEP3_CTRL & ~ ( bUEP_R_TOG | MASK_UEP_R_RES ) | UEP_R_RES_ACK;
                                break;
                            case 0x82:
                                UEP2_CTRL = UEP2_CTRL & ~ ( bUEP_T_TOG | MASK_UEP_T_RES ) | UEP_T_RES_NAK;
                                break;
                            case 0x02:
                                UEP2_CTRL = UEP2_CTRL & ~ ( bUEP_R_TOG | MASK_UEP_R_RES ) | UEP_R_RES_ACK;
                                break;
                            case 0x81:
                                UEP1_CTRL = UEP1_CTRL & ~ ( bUEP_T_TOG | MASK_UEP_T_RES ) | UEP_T_RES_NAK;
                                break;
                            case 0x01:
                                UEP1_CTRL = UEP1_CTRL & ~ ( bUEP_R_TOG | MASK_UEP_R_RES ) | UEP_R_RES_ACK;
                                break;
                            default:
                                len = 0xFF;                                         // 不支持的端点
                                break;
                            }
                        }
                        else
                        {
                            len = 0xFF;                                                // 不是端点不支持
                        }
                        break;
                    case USB_SET_FEATURE:                                          /* Set Feature */
                        if( ( UsbSetupBuf->bRequestType & 0x1F ) == USB_REQ_RECIP_DEVICE )                  /* 设置设备 */
                        {
                            if( ( ( ( uint16_t )UsbSetupBuf->wValueH << 8 ) | UsbSetupBuf->wValueL ) == 0x01 )
                            {
                                if( CfgDesc[ 7 ] & 0x20 )
                                {
                                    /* 休眠 */
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
void main()
{
    CfgFsys();
    mDelaymS(5);

    // Configure for external 3.3V LDO
    // When using external 3.3V power supply on VDD and V33 pins,
    // the internal LDO must be disabled to avoid conflicts
    SAFE_MOD = 0x55;
    SAFE_MOD = 0xAA;
    GLOBAL_CFG |= bLDO3V3_OFF;  // Disable internal LDO (bit 1 = 1)

    // Configure pin 3.2 as LED control
    P3_DIR_PU |= (1 << LED_PIN);
    P3_MOD_OC &= ~(1 << LED_PIN);
    LED = 1;  // Turn off LED initially (active low)

    // Configure pin 3.3 as FPGA_EN control (output)
    P3_DIR_PU |= (1 << FPGA_EN_PIN);
    P3_MOD_OC &= ~(1 << FPGA_EN_PIN);

    // Configure pin 1.0 as FPGA_RST control (output initially)
    // SPI pins will be configured on-demand by spi_bus_take_control()
    P1_MOD_OC = 0x00;
    P1_DIR_PU = 0;
    P1_DIR_PU |= (1 << FPGA_RST_PIN);  // Only FPGA_RST as output initially

    // Initialize SPI hardware (but pins remain in high-Z until needed)
    SPI0_SETUP = 0;                                                       //Master模式,高位在前
    SPI0_CTRL = 0x60;                                                     //模式0
    SPI0_CK_SE = 0x02;

    // Initialize FPGA in enabled state with SPI bus released (normal operation)
    spi_bus_release();  // SPI pins in high-Z, FPGA controls the bus
    FPGA_RST = 1;       // Release reset
    FPGA_EN = 1;        // Enable FPGA

    USBDeviceCfg();
    USBDeviceEndPointCfg();                                               // Endpoint configuration
    USBDeviceIntCfg();                                                    //Interrupt initialization
    UEP0_T_LEN = 0;
    UEP1_T_LEN = 0;                                                       //Pre-use send length must be cleared
    UEP2_T_LEN = 0;                                                       //Pre-use send length must be cleared

    while(!UsbConfig);
    LED = 1; // Turn off LED when USB configured (active low)
    
    while(1)
    {
        handle_command();
    }
}

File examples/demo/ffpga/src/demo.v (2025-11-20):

// ================================================================
//  DEMO:
//  Charlieplex 105-LED 15x7 Matrix + Ripple Effect Animation
//  With Button Controls
// ================================================================

(* top *)
module Demo #(
    parameter IN_CLK_HZ  = 50_000_000,
    parameter REFRESH_HZ = 1_000
) (
    (* iopad_external_pin *)
    input nreset,
    (* iopad_external_pin, clkbuf_inhibit *)
    input clk,
    (* iopad_external_pin *)
    output osc_en,

    // Button inputs (active high)
    (* iopad_external_pin *) input BTN1,  // Invert pattern
    (* iopad_external_pin *) input BTN2,  // Speed up
    (* iopad_external_pin *) input BTN3,  // Speed down
    (* iopad_external_pin *) input BTN4,  // Pause/Play

    // Charlieplex pins (11 pins)
    (* iopad_external_pin *) output CHARLIEPLEX_OE_0,
    (* iopad_external_pin *) output CHARLIEPLEX_PIN_0,
    (* iopad_external_pin *) output CHARLIEPLEX_OE_1,
    (* iopad_external_pin *) output CHARLIEPLEX_PIN_1,
    (* iopad_external_pin *) output CHARLIEPLEX_OE_2,
    (* iopad_external_pin *) output CHARLIEPLEX_PIN_2,
    (* iopad_external_pin *) output CHARLIEPLEX_OE_3,
    (* iopad_external_pin *) output CHARLIEPLEX_PIN_3,
    (* iopad_external_pin *) output CHARLIEPLEX_OE_4,
    (* iopad_external_pin *) output CHARLIEPLEX_PIN_4,
    (* iopad_external_pin *) output CHARLIEPLEX_OE_5,
    (* iopad_external_pin *) output CHARLIEPLEX_PIN_5,
    (* iopad_external_pin *) output CHARLIEPLEX_OE_6,
    (* iopad_external_pin *) output CHARLIEPLEX_PIN_6,
    (* iopad_external_pin *) output CHARLIEPLEX_OE_7,
    (* iopad_external_pin *) output CHARLIEPLEX_PIN_7,
    (* iopad_external_pin *) output CHARLIEPLEX_OE_8,
    (* iopad_external_pin *) output CHARLIEPLEX_PIN_8,
    (* iopad_external_pin *) output CHARLIEPLEX_OE_9,
    (* iopad_external_pin *) output CHARLIEPLEX_PIN_9,
    (* iopad_external_pin *) output CHARLIEPLEX_OE_10,
    (* iopad_external_pin *) output CHARLIEPLEX_PIN_10
);

    assign osc_en = 1'b1;

    // Bundle pins
    wire [10:0] oe_pins;
    wire [10:0] charlieplex_pins;

    assign CHARLIEPLEX_OE_0   = oe_pins[0];
    assign CHARLIEPLEX_PIN_0  = charlieplex_pins[0];
    assign CHARLIEPLEX_OE_1   = oe_pins[1];
    assign CHARLIEPLEX_PIN_1  = charlieplex_pins[1];
    assign CHARLIEPLEX_OE_2   = oe_pins[2];
    assign CHARLIEPLEX_PIN_2  = charlieplex_pins[2];
    assign CHARLIEPLEX_OE_3   = oe_pins[3];
    assign CHARLIEPLEX_PIN_3  = charlieplex_pins[3];
    assign CHARLIEPLEX_OE_4   = oe_pins[4];
    assign CHARLIEPLEX_PIN_4  = charlieplex_pins[4];
    assign CHARLIEPLEX_OE_5   = oe_pins[5];
    assign CHARLIEPLEX_PIN_5  = charlieplex_pins[5];
    assign CHARLIEPLEX_OE_6   = oe_pins[6];
    assign CHARLIEPLEX_PIN_6  = charlieplex_pins[6];
    assign CHARLIEPLEX_OE_7   = oe_pins[7];
    assign CHARLIEPLEX_PIN_7  = charlieplex_pins[7];
    assign CHARLIEPLEX_OE_8   = oe_pins[8];
    assign CHARLIEPLEX_PIN_8  = charlieplex_pins[8];
    assign CHARLIEPLEX_OE_9   = oe_pins[9];
    assign CHARLIEPLEX_PIN_9  = charlieplex_pins[9];
    assign CHARLIEPLEX_OE_10  = oe_pins[10];
    assign CHARLIEPLEX_PIN_10 = charlieplex_pins[10];

    // Debounced button signals and edge detection
    wire btn1_db, btn2_db, btn3_db, btn4_db;
    wire btn1_press, btn2_press, btn3_press, btn4_press;

    // Debounce all buttons
    button_debounce #(.CLK_HZ(IN_CLK_HZ)) db1 (.clk(clk), .nreset(nreset), .btn_in(BTN1), .btn_out(btn1_db));
    button_debounce #(.CLK_HZ(IN_CLK_HZ)) db2 (.clk(clk), .nreset(nreset), .btn_in(BTN2), .btn_out(btn2_db));
    button_debounce #(.CLK_HZ(IN_CLK_HZ)) db3 (.clk(clk), .nreset(nreset), .btn_in(BTN3), .btn_out(btn3_db));
    button_debounce #(.CLK_HZ(IN_CLK_HZ)) db4 (.clk(clk), .nreset(nreset), .btn_in(BTN4), .btn_out(btn4_db));

    // Edge detection for button presses
    edge_detect ed1 (.clk(clk), .nreset(nreset), .signal(btn1_db), .edge_pulse(btn1_press));
    edge_detect ed2 (.clk(clk), .nreset(nreset), .signal(btn2_db), .edge_pulse(btn2_press));
    edge_detect ed3 (.clk(clk), .nreset(nreset), .signal(btn3_db), .edge_pulse(btn3_press));
    edge_detect ed4 (.clk(clk), .nreset(nreset), .signal(btn4_db), .edge_pulse(btn4_press));

    // LED Scanner with button controls
    led_scanner #(
        .IN_CLK_HZ(IN_CLK_HZ),
        .REFRESH_HZ(REFRESH_HZ)
    ) scanner (
        .clk(clk),
        .nreset(nreset),
        .btn_invert(btn1_press),
        .btn_speed_up(btn2_press),
        .btn_speed_down(btn3_press),
        .btn_pause(btn4_press),
        .oe_pins(oe_pins),
        .charlieplex_pins(charlieplex_pins)
    );

endmodule


// ================================================================
//  Button Debouncer (20ms debounce time)
// ================================================================
module button_debounce #(
    parameter CLK_HZ = 50_000_000
)(
    input clk,
    input nreset,
    input btn_in,
    output reg btn_out
);
    localparam DEBOUNCE_MS = 20;
    localparam CNT_MAX     = (CLK_HZ / 1_000) * DEBOUNCE_MS;
    localparam CNT_WIDTH   = $clog2(CNT_MAX + 1);

    reg [CNT_WIDTH-1:0] counter;
    reg btn_sync_0, btn_sync_1;

    always @(posedge clk) begin
        if (!nreset) begin
            btn_sync_0 <= 0;
            btn_sync_1 <= 0;
            btn_out    <= 0;
            counter    <= 0;
        end else begin
            // Synchronizer
            btn_sync_0 <= btn_in;
            btn_sync_1 <= btn_sync_0;

            // Debounce logic
            if (btn_sync_1 == btn_out) begin
                counter <= 0;
            end else begin
                counter <= counter + 1;
                if (counter >= CNT_MAX) begin
                    btn_out <= btn_sync_1;
                    counter <= 0;
                end
            end
        end
    end
endmodule


// ================================================================
//  Edge Detector (rising edge)
// ================================================================
module edge_detect (
    input clk,
    input nreset,
    input signal,
    output reg edge_pulse
);
    reg signal_delayed;

    always @(posedge clk) begin
        if (!nreset) begin
            signal_delayed <= 0;
            edge_pulse     <= 0;
        end else begin
            signal_delayed <= signal;
            edge_pulse     <= signal && !signal_delayed;
        end
    end
endmodule
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

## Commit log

2025-11-04 Add Hardware documentation
    [3D.step, BOM.csv, PickAndPlace.csv]
2025-11-05 Disable internal LDO when using external 3.3V supply
    Added code to disable the internal 3.3V LDO when an external 3.3V power supply is used on VDD and V33 pins. This prevents conflicts between the internal and external power sources.
    [main.c]
2025-11-06 Add 11-pin charlieplexing FPGA module
    Introduces Verilog modules for 11-pin charlieplexing to drive up to 105 LEDs, including multiplexing logic and GPIO mappings. Updates .gitignore to exclude the fpga directory.
2025-11-08 Update README.md to reflect completed PCB layout and CH552 firmware implementation; remove examples directory placeholder
2025-11-20 v2.0.0 - Major Reorganization & Firmware Improvements
    ## Project Structure
    - Reorganized FPGA examples from fpga/ to examples/ directory
    - Separated blink and demo examples into individual project folders
    - Added blink example with simple LED control (2Hz, 2 GPIO pins)
    - Updated demo example with full 105-LED Charlieplex matrix
    - Cleaned up bitstream files: only track flash-specific binaries
    ## Firmware (CH552)
    - Fixed LED behavior: LED now stays off when USB not enumerated
    - Improved user experience: LED only blinks during flash operations
    - Updated firmware binary with latest changes
    ## Verilog Code Quality
    - Standardized Verilog coding style across both examples
    - Consistent parameter f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
    [demo.v, main.c]

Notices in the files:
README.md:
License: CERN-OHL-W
